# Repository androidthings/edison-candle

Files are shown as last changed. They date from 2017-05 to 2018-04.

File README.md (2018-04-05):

Edison Candle
=============
The Edison Candle is an example of building a production device using a
System-on-Module (SoM) running Android Things.
This repository contains the application software.
You can find the hardware schematic, layout, and bill of materials (BOM) hosted
on [CircuitHub](https://circuithub.com/projects/androidthings/edison-candle).

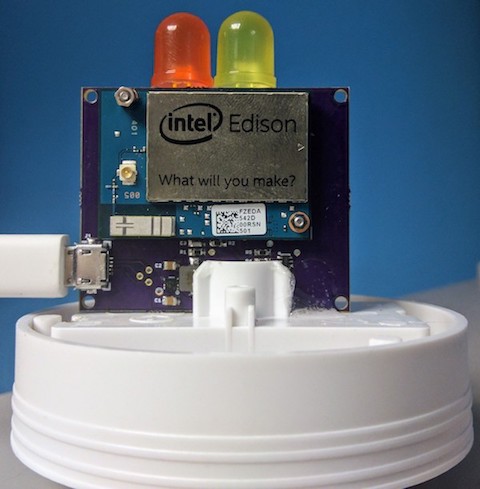
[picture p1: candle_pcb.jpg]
Edison Candle Hardware


Prerequisites
-------------

- Carrier board from
  [CircuitHub](https://circuithub.com/projects/androidthings/edison-candle)
- Edison compute module ([SparkFun](https://www.sparkfun.com/products/13024))
- Edison mounting hardware ([SparkFun](https://www.sparkfun.com/products/13187))
- Orange LED ([SparkFun](https://www.sparkfun.com/products/12645))
- Yellow LED ([SparkFun](https://www.sparkfun.com/products/10634))
- Android Studio 2.2+

Getting Started
----------------

1.  Assemble the hardware components
2.  Import the project into Android Studio
3.  Connect the Edison to USB
4.  In Android Studio, click on the "Run" button.

If you prefer to run on the command line, type
```bash
./gradlew installDebug
adb shell am start com.example.androidthings.candle/.HomeActivity
```

Prototype Schematic
--------------------

You may also choose to run the sample on an Edison developer kit, with the
necessary peripherals connected as shown below:

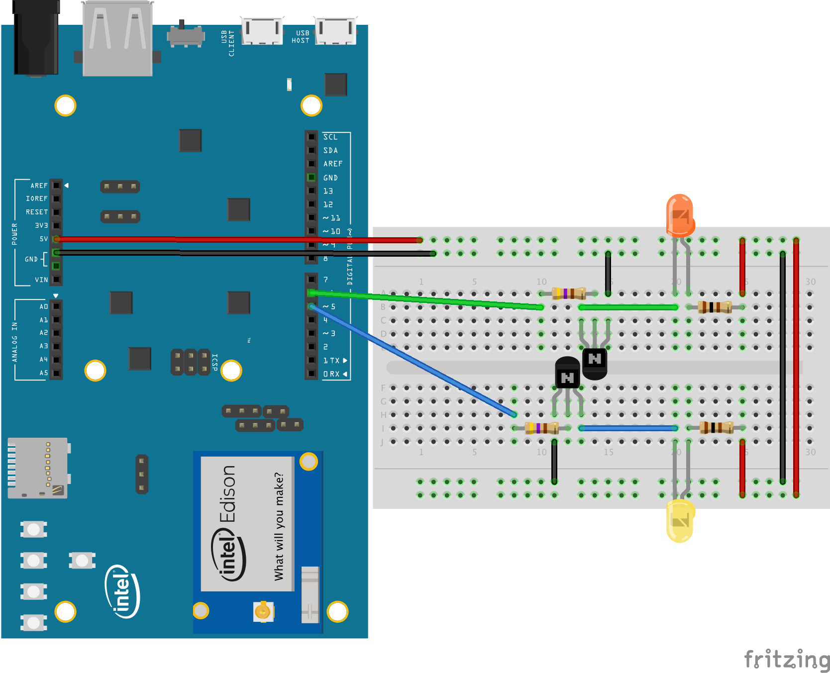
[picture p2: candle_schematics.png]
Schematic for Edison Candle Prototype


Enable auto-launch behavior
---------------------------

This sample app is currently configured to launch only when deployed from your
development machine. To enable the main activity to launch automatically on boot,
add the following `intent-filter` to the app's manifest file:

```xml
<activity ...>

    <intent-filter>
        <action android:name="android.intent.action.MAIN"/>
        <category android:name="android.intent.category.HOME"/>
        <category android:name="android.intent.category.DEFAULT"/>
    </intent-filter>

</activity>
```

License
-------

Copyright 2017 The Android Open Source Project, Inc.

Licensed to the Apache Software Foundation (ASF) under one or more contributor
license agreements.  See the NOTICE file distributed with this work for
additional information regarding copyright ownership.  The ASF licenses this
file to you under the Apache License, Version 2.0 (the "License"); you may not
use this file except in compliance with the License.  You may obtain a copy of
the License at

  http://www.apache.org/licenses/LICENSE-2.0

Unless required by applicable law or agreed to in writing, software
distributed under the License is distributed on an "AS IS" BASIS, WITHOUT
WARRANTIES OR CONDITIONS OF ANY KIND, either express or implied.  See the
License for the specific language governing permissions and limitations under
the License.

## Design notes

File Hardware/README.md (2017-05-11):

Edison Candle Hardware
======================

This directory contains the hardware design files for the Edison Candle
production carrier board. The current revision was built using EAGLE.

Libraries
---------

The following EAGLE libraries were used in this design:

-   [SparkFun Blocks Template](https://github.com/sparkfun/Sparkfun_Blocks_Template)
    -   Provides Edison compute module and PCB footprint.
-   [SparkFun Eagle Libraries](https://github.com/sparkfun/SparkFun-Eagle-Libraries)
    -   Provides common components, such as the USB Micro connector.

License
-------

The hardware design files are released under the
[Creative Commons 4.0 International](http://creativecommons.org/licenses/by/4.0/)
license.

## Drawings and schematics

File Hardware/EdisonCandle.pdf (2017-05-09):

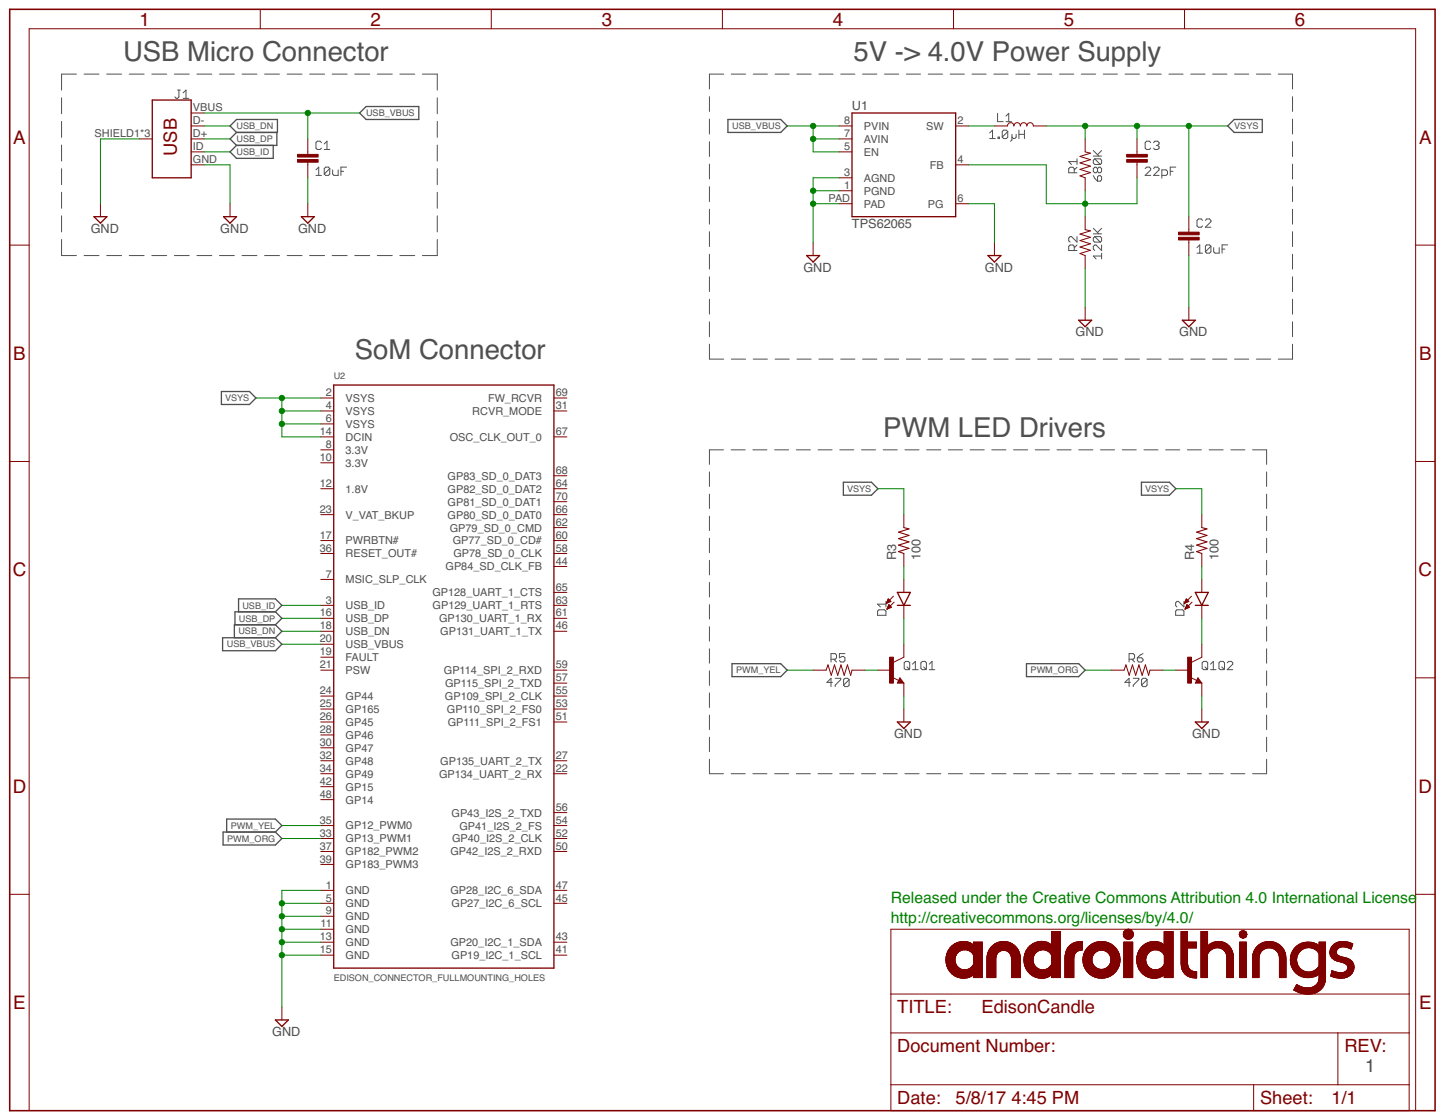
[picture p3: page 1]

Released under the Creative Commons Attribution 4.0 International License
http://creativecommons.org/licenses/by/4.0/

Document Number: | REV: 1

Date: 5/8/17 4:45 PM | Sheet: 1/1

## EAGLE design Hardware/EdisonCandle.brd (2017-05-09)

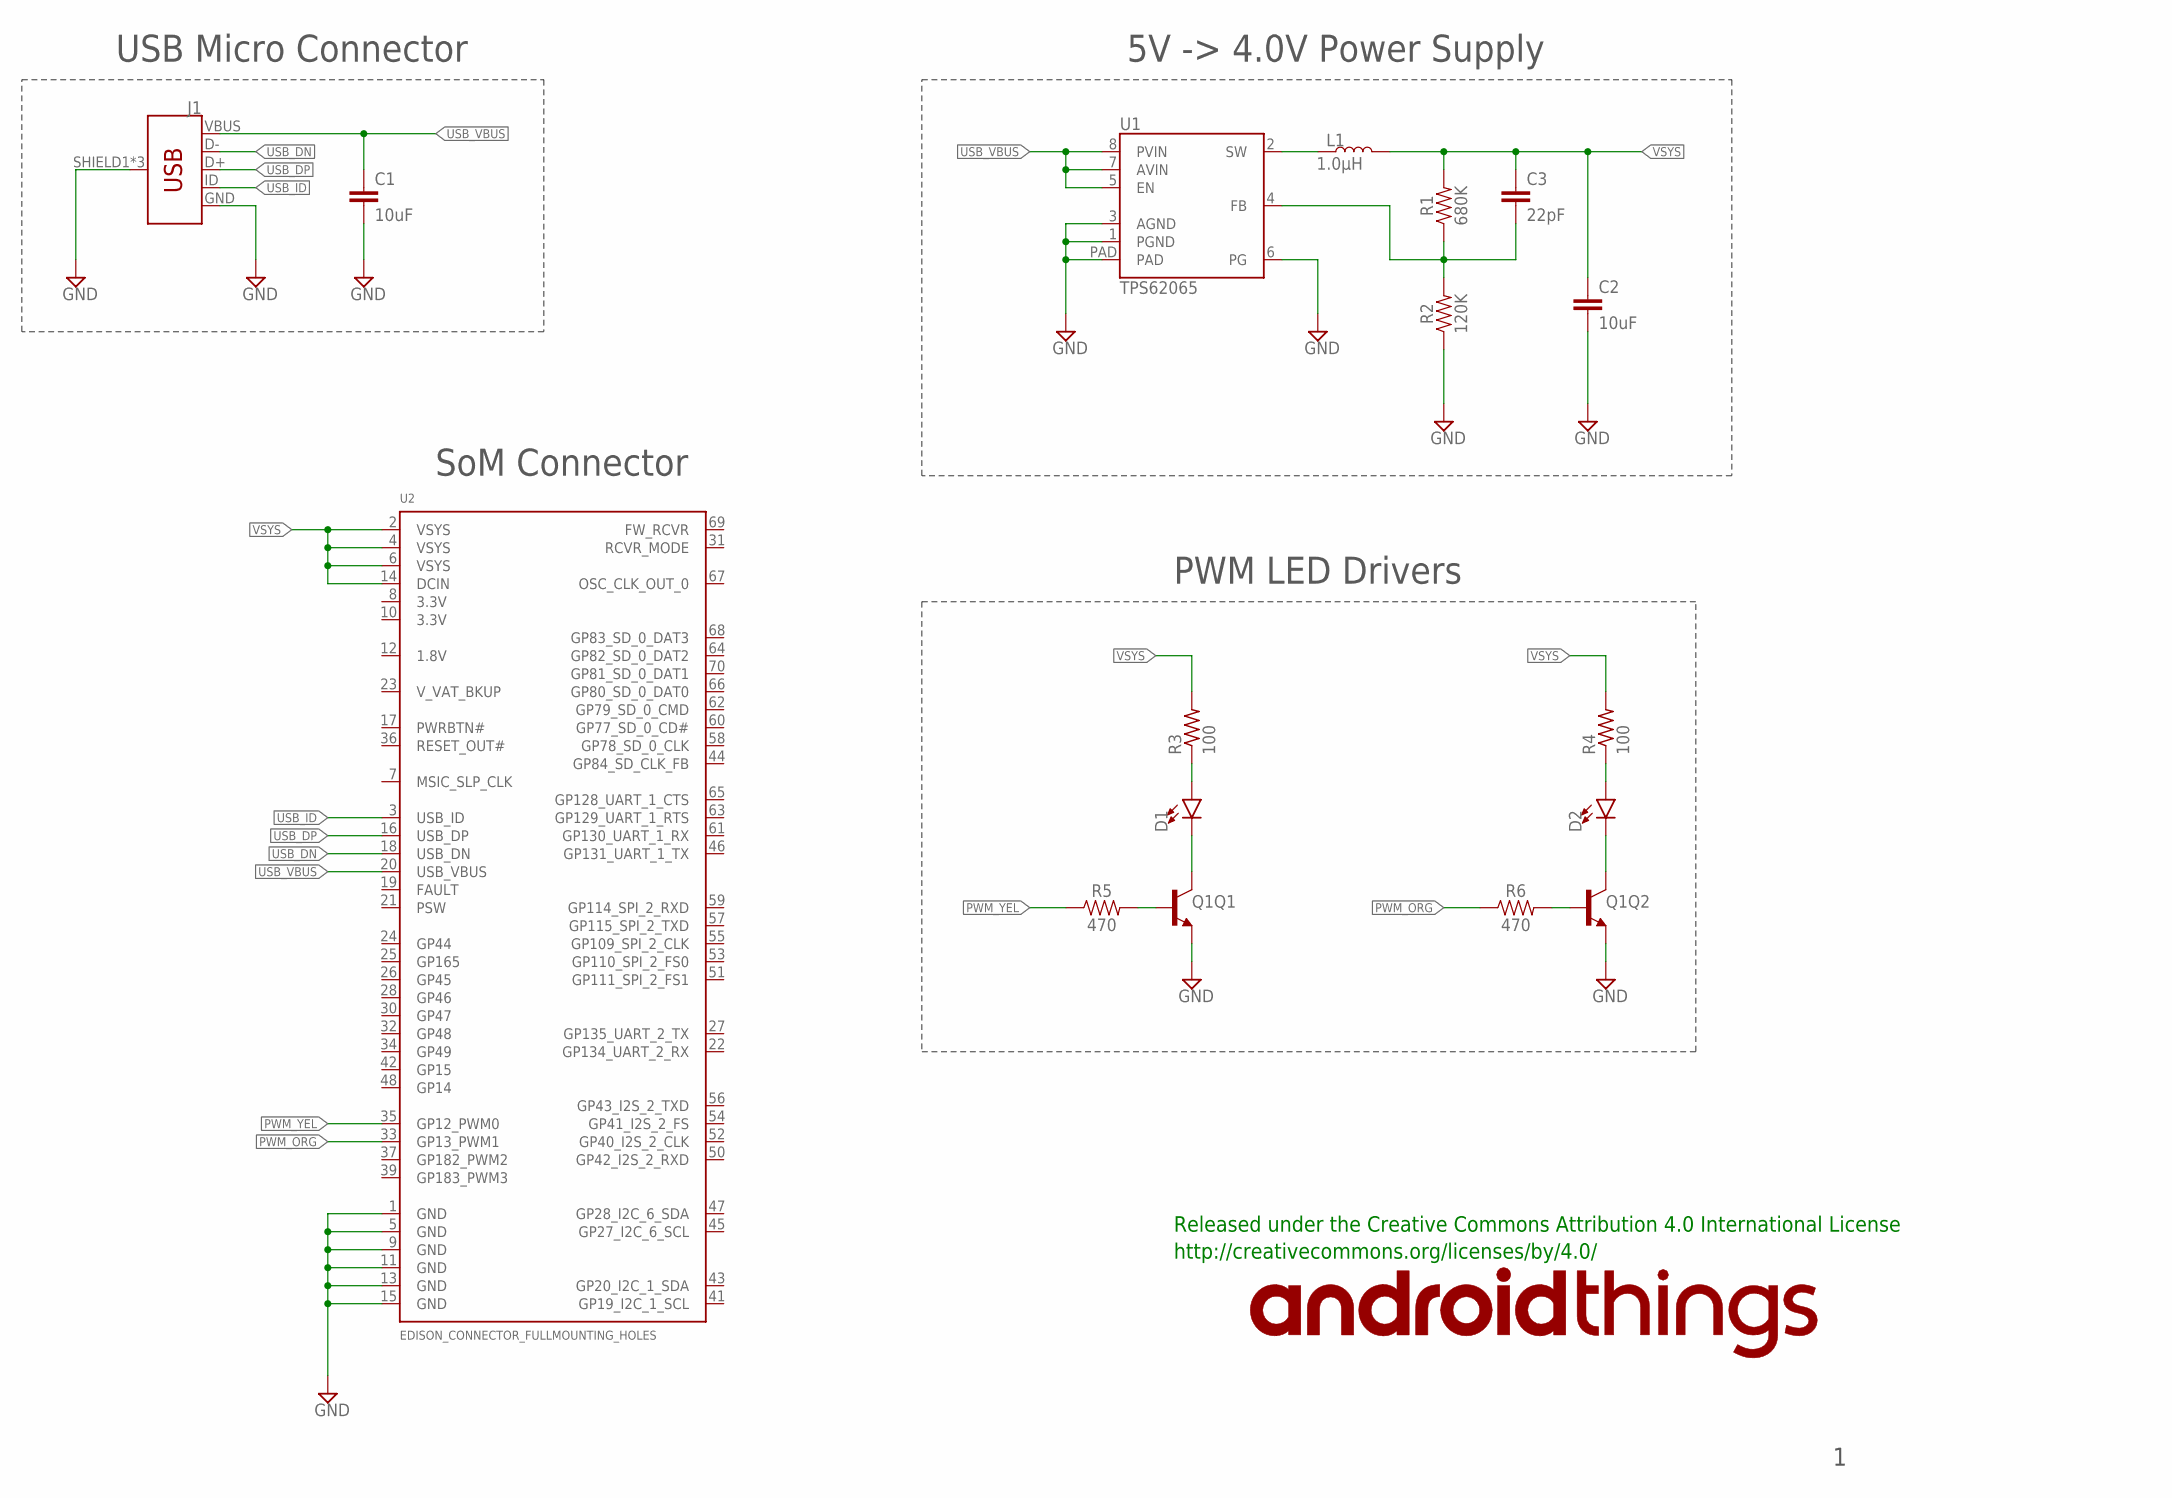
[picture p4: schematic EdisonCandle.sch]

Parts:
C1, C2: 10uF; 0805; MPN GRM21BR71A106KE51K
C3: 22pF; 0603; MPN 06035C220JAT2A
D1, D2: LED10MM; LED_10MM
J1: USB_MICRO-B_FEMALE-SMT; USB-B-MICRO-SMD; MPN 10104110-0001LF
L1: 1.0µH; SRP4020; MPN SRP4020-1R0M
Q1: TRANS_NPN_DUAL-MBT3904DW1T1; SC70-6; MPN MBT3904DW1T1G
R1: 680K; 0603; MPN ERJ-3EKF6803V
R2: 120K; 0603; MPN ERJ-3EKF1203V
R3, R4: 100; M1206; MPN RC1206FR-07100RL
R5, R6: 470; 0603; MPN ERJ-3EKF4700V
U1: TPS62065; WSON-8-PAD; MPN TPS62065DSGR
U2: EDISON_CONNECTOR_FULLMOUNTING_HOLES; EDISON_DAUGHTER; MPN DF40HC(3.0)-70DS-0.4V(58)

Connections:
GND: C1.2, C2.2, J1.GND, J1.SHIELD1 (SHIELD), J1.SHIELD2 (SHIELD), J1.SHIELD3 (SHIELD), Q1.1 (E), Q1.4 (E), R2.1, U1.1 (PGND), U1.3 (AGND), U1.6 (PG), U1.PAD, U2.1 (GND), U2.5 (GND), U2.9 (GND), U2.11 (GND), U2.13 (GND), U2.15 (GND)
unnamed: L1.1, U1.2 (SW)
unnamed: D1.A, R3.1
unnamed: C3.2, R1.1, R2.2, U1.4 (FB)
unnamed: D2.A, R4.1
unnamed: D1.C, Q1.3 (C)
unnamed: D2.C, Q1.6 (C)
unnamed: Q1.5 (B), R5.2
unnamed: Q1.2 (B), R6.2
PWM_ORG: R6.1, U2.33 (GP13_PWM1)
PWM_YEL: R5.1, U2.35 (GP12_PWM0)
USB_DN: J1.D-, U2.18 (USB_DN)
USB_DP: J1.D+, U2.16 (USB_DP)
USB_ID: J1.ID, U2.3 (USB_ID)
USB_VBUS: C1.1, J1.VBUS, U1.5 (EN), U1.7 (AVIN), U1.8 (PVIN), U2.20 (USB_VBUS)
VSYS: C2.1, C3.1, L1.2, R1.2, R3.2, R4.2, U2.2 (VSYS), U2.4 (VSYS), U2.6 (VSYS), U2.14 (DCIN)

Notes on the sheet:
SoM Connector
PWM LED Drivers
USB Micro Connector
5V -> 4.0V Power Supply
Released under the Creative Commons Attribution 4.0 International License
http://creativecommons.org/licenses/by/4.0/

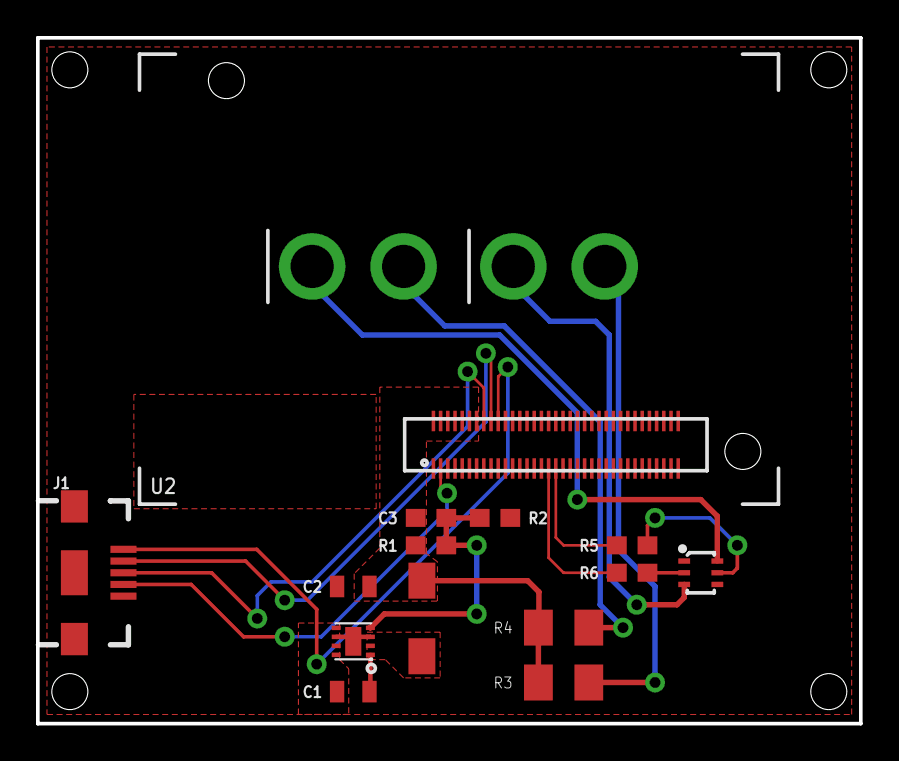
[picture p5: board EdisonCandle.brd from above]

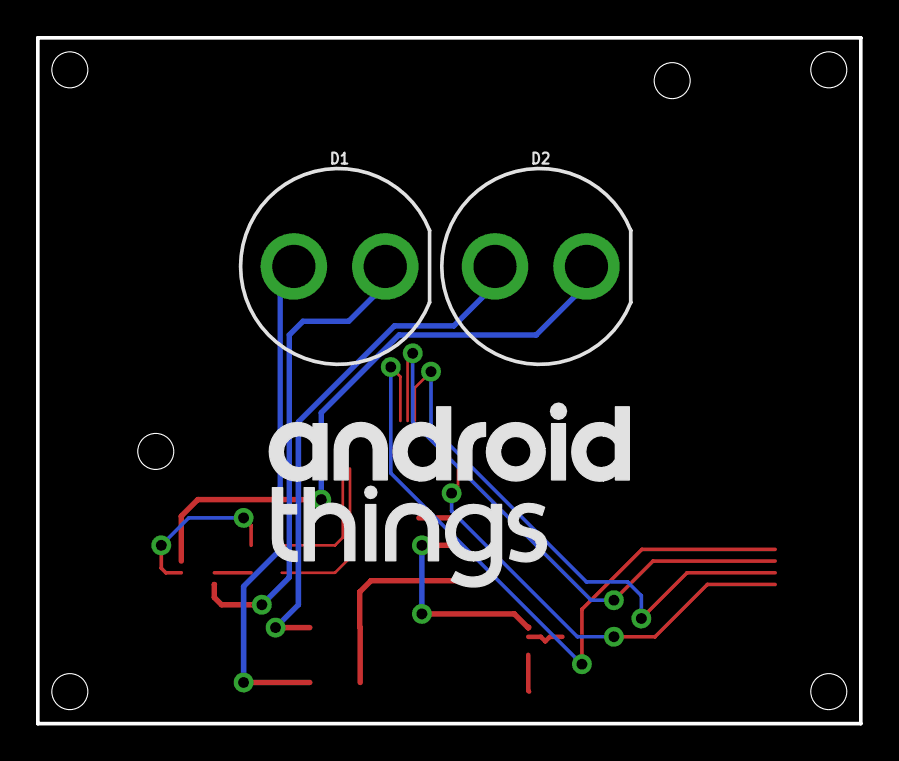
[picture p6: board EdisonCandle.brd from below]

Board: 2 copper layers, 45.7 x 38.1 mm, 17 parts (3 on the bottom side), 16 nets.

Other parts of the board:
U$2: ATHINGS_LOGO_STACKED_20MM

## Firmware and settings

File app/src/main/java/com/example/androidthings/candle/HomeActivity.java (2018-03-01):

/*
 * Copyright 2017, The Android Open Source Project
 *
 * Licensed under the Apache License, Version 2.0 (the "License");
 * you may not use this file except in compliance with the License.
 * You may obtain a copy of the License at
 *
 *      http://www.apache.org/licenses/LICENSE-2.0
 *
 * Unless required by applicable law or agreed to in writing, software
 * distributed under the License is distributed on an "AS IS" BASIS,
 * WITHOUT WARRANTIES OR CONDITIONS OF ANY KIND, either express or implied.
 * See the License for the specific language governing permissions and
 * limitations under the License.
 */

package com.example.androidthings.candle;

import android.animation.ObjectAnimator;
import android.animation.ValueAnimator;
import android.app.Activity;
import android.os.Bundle;
import android.util.Log;
import android.view.animation.BounceInterpolator;

import com.google.android.things.pio.PeripheralManager;
import com.google.android.things.pio.Pwm;

import java.io.IOException;

/**
 * Implement a flickering candle using LEDs connected to PWM
 * and a simple ObjectAnimator.
 */
public class HomeActivity extends Activity {
    private static final String TAG = "EdisonCandle";

    // PWM output pin names
    private static final String YELLOW_PWM = BoardDefaults.getYellowPwmPort();
    private static final String ORANGE_PWM = BoardDefaults.getOrangePwmPort();
    // Brightness values
    private static final float BRIGHTNESS_START = 25f;
    private static final float BRIGHTNESS_END = 100f;
    // Animation duration
    private static final int DURATION_MS = 350;
    // Offset between animations to give the candle more life
    private static final int DELAY_MS = 150;

    private Pwm mYellowLed, mOrangeLed;
    private ObjectAnimator mYellowFlame, mOrangeFlame;

    @Override
    protected void onCreate(Bundle savedInstanceState) {
        super.onCreate(savedInstanceState);

        try {
            mYellowLed = openLed(YELLOW_PWM);
            mOrangeLed = openLed(ORANGE_PWM);
        } catch (IOException e) {
            Log.w(TAG, "Unable to open LED connections", e);
        }

        // Create an run the flicker animations
        mYellowFlame = animateFlicker(mYellowLed, 0);
        mOrangeFlame = animateFlicker(mOrangeLed, DELAY_MS);
        mYellowFlame.start();
        mOrangeFlame.start();
    }

    @Override
    public void onDestroy() {
        super.onDestroy();

        mYellowFlame.cancel();
        mOrangeFlame.cancel();

        try {
            closeLed(mYellowLed);
            closeLed(mOrangeLed);
        } catch (IOException e) {
            Log.w(TAG, "Unable to close LED connections", e);
        }
    }

    /**
     * Open a new LED connection to the provided port name
     * @throws IOException
     */
    private Pwm openLed(String name) throws IOException {
        Pwm led = PeripheralManager.getInstance().openPwm(name);
        led.setPwmFrequencyHz(60.0f);
        led.setPwmDutyCycle(BRIGHTNESS_START);
        led.setEnabled(true);

        return led;
    }

    /**
     * Close the provided PWM connection
     * @throws IOException
     */
    private void closeLed(Pwm pwm) throws IOException {
        if (pwm != null) {
            pwm.setEnabled(false);
            pwm.close();
        }
    }

    /**
     * Create an infinite animation to modify the LED brightness.
     */
    private ObjectAnimator animateFlicker(Pwm led, long delay) {
        ObjectAnimator animator = ObjectAnimator
                .ofFloat(led, new BrightnessProperty(), BRIGHTNESS_START, BRIGHTNESS_END)
                .setDuration(DURATION_MS + delay);

        // "Bounce" at each end to create a flicker effect
        animator.setInterpolator(new BounceInterpolator());
        // Cycle through the animation forever
        animator.setRepeatMode(ValueAnimator.REVERSE);
        animator.setRepeatCount(ValueAnimator.INFINITE);

        return animator;
    }

}

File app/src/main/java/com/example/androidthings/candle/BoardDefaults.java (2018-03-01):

/*
 * Copyright 2017, The Android Open Source Project
 *
 * Licensed under the Apache License, Version 2.0 (the "License");
 * you may not use this file except in compliance with the License.
 * You may obtain a copy of the License at
 *
 *      http://www.apache.org/licenses/LICENSE-2.0
 *
 * Unless required by applicable law or agreed to in writing, software
 * distributed under the License is distributed on an "AS IS" BASIS,
 * WITHOUT WARRANTIES OR CONDITIONS OF ANY KIND, either express or implied.
 * See the License for the specific language governing permissions and
 * limitations under the License.
 */

package com.example.androidthings.candle;

import android.os.Build;

import com.google.android.things.pio.PeripheralManager;

import java.util.List;

public class BoardDefaults {
    private static final String DEVICE_EDISON_ARDUINO = "edison_arduino";
    private static final String DEVICE_EDISON = "edison";
    private static String sBoardVariant = "";
    /**
     * Return the preferred PWM port for the Yellow LED.
     */
    public static String getYellowPwmPort() {
        switch (getBoardVariant()) {
            case DEVICE_EDISON_ARDUINO:
                return "IO5";
            case DEVICE_EDISON:
                return "GP12";
            default:
                throw new IllegalStateException("Unknown Build.DEVICE " + Build.DEVICE);
        }
    }

    /**
     * Return the preferred PWM port for the Orange LED.
     */
    public static String getOrangePwmPort() {
        switch (getBoardVariant()) {
            case DEVICE_EDISON_ARDUINO:
                return "IO6";
            case DEVICE_EDISON:
                return "GP13";
            default:
                throw new IllegalStateException("Unknown Build.DEVICE " + Build.DEVICE);
        }
    }

    private static String getBoardVariant() {
        if (!sBoardVariant.isEmpty()) {
            return sBoardVariant;
        }
        sBoardVariant = Build.DEVICE;
        // For the edison check the pin prefix
        // to always return Edison Breakout pin name when applicable.
        if (sBoardVariant.equals(DEVICE_EDISON)) {
            List<String> gpioList = PeripheralManager.getInstance().getGpioList();
            if (gpioList.size() != 0) {
                String pin = gpioList.get(0);
                if (pin.startsWith("IO")) {
                    sBoardVariant = DEVICE_EDISON_ARDUINO;
                }
            }
        }
        return sBoardVariant;
    }
}

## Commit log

2017-05-09 Initial production candle sample.
    [EdisonCandle.brd, EdisonCandle.sch, candle_schematic.fzz]
2017-05-09 Include readable hardware schematic version.
2017-10-10 Move prototype schematics.
    [candle_schematics.fzz]
2017-10-10 Remove nested app directory.
    [candle_schematics.fzz]
2018-03-01 Update to android things sdk 0.7 and new drivers
    Updated to use Android Things SDK 0.7-devpreview
    Updated to the API changes in DP7
    Bug: 71717279
    [BoardDefaults.java, HomeActivity.java]

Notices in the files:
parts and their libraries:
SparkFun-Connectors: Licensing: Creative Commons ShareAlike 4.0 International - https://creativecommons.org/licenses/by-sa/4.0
